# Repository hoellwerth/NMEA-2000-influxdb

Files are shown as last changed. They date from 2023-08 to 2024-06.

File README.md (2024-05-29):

# NMEA-2000-influxdb
An esp32 which posts traffic in the NMEA 2000 BUS to an InfluxDB 2.7 instance.

## Table of contents

- [Electrical](/Electrical): A KiCad project
- [Mechanical](/Mechanical): 3D files for casing etc.
- [Software](/Software): Platform IO Files

## Features

- [x] Listen for all known PGNs
- [x] Post data to an InfluxDB 2.7 instance
- [x] Save data to an SD-Card while offline 
- [ ] Use wifimanager

## Contribution

If you want to help with a feature or add something, just fork the repository, make your changes and open a Pull Request

## License

This project ist licensed under the [GNU GENERAL PUBLIC LICENSE](/LICENSE)

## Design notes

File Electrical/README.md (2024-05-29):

# Electrical

## Table of Contents
- [Electrical](https://github.com/hoellwerth/NMEA-2000-influxdb/tree/master/Electrical#electrical)
  - [Schematic](https://github.com/hoellwerth/NMEA-2000-influxdb/blob/master/Electrical/production/schematic.pdf) The KiCad Schematic

## Components-List

A list of all the electrical components I used for the project:

- ESP32-WROOM-32E
- CAN-Transeiver SN65HVD230
- SD-Card Slot
- LM7805
- AMS1117
- BME280

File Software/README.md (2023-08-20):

# Software

## Table of Contents

- [Software](#software)
  - [Table of Contents](#table-of-contents)
  - [Introduction](#introduction)
  - [Usage](#usage)
  - [Libraries](#libraries)
  - [How it works](#how-it-works)

## Introduction

This scipt is based on PlatformIO and will read all the data in the NMEA-2000 (N2k) BUS and will send it to an InfluxDB database. As this thing will be mainly operated in a marine environment, it will save data on an SD-Card as the boat will not always be connected to the internet and then write it to the database when it gets reconnected to a Wifi in harbor.

## Usage

To use this script, you will need to have a running InfluxDB instance. You can use the docker-compose combination of InfluxDB, Grafana and Telegraf from [here](https://github.com/nicolargo/docker-influxdb-grafana). You will also need to have a running N2k BUS. If you want to know which Hardware in particular, you can check out the [Hardware](../Hardware/README.md) section.

## Libraries

This script uses the following libraries:

- [ArduinoJson](https://arduinojson.org/)
- [InfluxDB-Client-for-Arduino](https://github.com/tobiasschuerg/InfluxDB-Client-for-Arduino)
- [NMEA2000](https://github.com/ttlappalainen/NMEA2000)
- [NMEA2000_esp32](https://github.com/ttlappalainen/NMEA2000_esp32)
- [RTCLib](https://github.com/adafruit/RTClib?utm_source=platformio&utm_medium=piohome)
- [Time](https://github.com/PaulStoffregen/Time?utm_source=platformio&utm_medium=piohome)

The relevant section in **platformio.ini**:
```
lib_deps = 
	tobiasschuerg/ESP8266 Influxdb@^3.13.1
	ttlappalainen/NMEA2000-library@^4.18.7
	ttlappalainen/NMEA2000_esp32@^1.0.3
	bblanchon/ArduinoJson@^6.21.2
	Wire
	paulstoffregen/Time@^1.6.1
	adafruit/RTClib@^2.1.1
```

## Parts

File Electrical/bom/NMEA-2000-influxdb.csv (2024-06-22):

Reference | Value | Datasheet | Footprint | Qty | DNP
C1,C3,C5,C6,C8,C9 | 0.1uF | ~ | Capacitor_THT:C_Disc_D5.0mm_W2.5mm_P5.00mm | 6
C2 | 0.1nF | ~ | Capacitor_THT:C_Disc_D5.0mm_W2.5mm_P5.00mm | 1
C4,C10,C11 | 22uF | ~ | Capacitor_THT:C_Radial_D4.0mm_H7.0mm_P1.50mm | 3
C7 | 0.33uF | ~ | Capacitor_THT:C_Disc_D5.0mm_W2.5mm_P5.00mm | 1
D1 | LED_Small | ~ | LED_THT:LED_D3.0mm | 1
D2,D3,D4,D5 | LED | ~ | LED_THT:LED_D3.0mm | 4
F1 | Polyfuse | ~ | Diode_SMD:D_1210_3225Metric_Pad1.42x2.65mm_HandSolder | 1
J1,J2,J3 | Conn_01x04 | ~ | -- mixed values -- | 3
J4 | Conn_01x03 | ~ | Connector_PinHeader_2.54mm:PinHeader_1x03_P2.54mm_Vertical | 1
J5 | Conn_02x08 | ~ | Connector_IDC:IDC-Header_2x08_P2.54mm_Vertical | 1
J6 | Micro_SD_Card | http://katalog.we-online.de/em/datasheet/693072010801.pdf | Connector_Card:microSD_HC_Hirose_DM3AT-SF-PEJM5 | 1
JP1,JP4 | Jumper_2_Open | ~ | Connector_PinHeader_2.54mm:PinHeader_1x02_P2.54mm_Vertical | 2
JP2,JP3 | Jumper_3_Bridged12 | ~ | Connector_PinHeader_2.54mm:PinHeader_1x03_P2.54mm_Vertical | 2
R1,R3,R5 | 10k | ~ | Resistor_THT:R_Axial_DIN0207_L6.3mm_D2.5mm_P10.16mm_Horizontal | 3
R2 | 3.3k | ~ | Resistor_THT:R_Axial_DIN0207_L6.3mm_D2.5mm_P10.16mm_Horizontal | 1
R4,R10 | 330R | ~ | Resistor_THT:R_Axial_DIN0207_L6.3mm_D2.5mm_P10.16mm_Horizontal | 2
R6 | 1.5k | ~ | Resistor_THT:R_Axial_DIN0207_L6.3mm_D2.5mm_P10.16mm_Horizontal | 1
R7 | 1.2k | ~ | Resistor_THT:R_Axial_DIN0207_L6.3mm_D2.5mm_P10.16mm_Horizontal | 1
R8 | 120R | ~ | Resistor_THT:R_Axial_DIN0207_L6.3mm_D2.5mm_P10.16mm_Horizontal | 1
R9 | 500R | ~ | Resistor_THT:R_Axial_DIN0207_L6.3mm_D2.5mm_P10.16mm_Horizontal | 1
SW1 | SW_Push | ~ | Button_Switch_THT:SW_PUSH_6mm | 1
U1 | BMP280 | https://ae-bst.resource.bosch.com/media/_tech/media/datasheets/BST-BMP280-DS001.pdf | Package_LGA:Bosch_LGA-8_2x2.5mm_P0.65mm_ClockwisePinNumbering | 1
U2 | LM7805_TO220 | https://www.onsemi.cn/PowerSolutions/document/MC7800-D.PDF | Package_TO_SOT_THT:TO-220-3_Vertical | 1
U3 | ESP32-WROOM-32E | https://www.espressif.com/sites/default/files/documentation/esp32-wroom-32e_esp32-wroom-32ue_datasheet_en.pdf | RF_Module:ESP32-WROOM-32D | 1
U4 | AMS1117-3.3 | http://www.advanced-monolithic.com/pdf/ds1117.pdf | Package_TO_SOT_SMD:SOT-223-3_TabPin2 | 1
U5 | SN65HVD230 | http://www.ti.com/lit/ds/symlink/sn65hvd230.pdf | Package_SO:SOIC-8_3.9x4.9mm_P1.27mm | 1

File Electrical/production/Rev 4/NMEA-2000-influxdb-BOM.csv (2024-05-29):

Reference | Value | Datasheet | Footprint | Qty | DNP | LCSC Part Number | Sourced
C1 | 0.33uF | ~ | Capacitor_THT:C_Disc_D5.0mm_W2.5mm_P5.00mm | 1 |  | C2761750 | yes
C2,C5,C8,C9,C10 | 0.1uF | ~ | Capacitor_THT:C_Disc_D5.0mm_W2.5mm_P5.00mm | 5 |  | C84772 | yes
C3,C4,C6 | 1uF | ~ | Capacitor_THT:C_Disc_D5.0mm_W2.5mm_P5.00mm | 3 |  | C5632429 | yes
C7 | 22uF | ~ | Capacitor_SMD:C_1206_3216Metric_Pad1.33x1.80mm_HandSolder | 1 |  | C12891 | yes
D1,D2,D3,D4,D5 | LED | ~ | LED_THT:LED_D3.0mm | 5 |  |  | yes
F1 | Polyfuse | ~ | Diode_SMD:D_1210_3225Metric_Pad1.42x2.65mm_HandSolder | 1 |  | C720080 | yes
J1 | Conn_01x04 | ~ | Connector:FanPinHeader_1x04_P2.54mm_Vertical | 1 |  |  | yes
J2 | DE9_Receptacle | ~ | Connector_Dsub:DSUB-9_Female_Horizontal_P2.77x2.84mm_EdgePinOffset9.90mm_Housed_MountingHolesOffset11.32mm | 1 |  | C19077337 | yes
J3 | Conn_01x04 |  | TerminalBlock_Phoenix:TerminalBlock_Phoenix_PT-1,5-4-5.0-H_1x04_P5.00mm_Horizontal | 1 |  |  | yes
J4 | Micro_SD_Card | http://katalog.we-online.de/em/datasheet/693072010801.pdf | Connector_Card:microSD_HC_Hirose_DM3AT-SF-PEJM5 | 1 |  | C114218 | yes
J5 | Conn_02x08 | ~ | Connector_IDC:IDC-Header_2x08_P2.54mm_Vertical | 1 |  |  | yes
JP1 | Jumper_2_Open | ~ | Connector_PinHeader_2.54mm:PinHeader_1x02_P2.54mm_Vertical | 1 |  |  | yes
JP2,JP3 | Jumper_3_Bridged12 | ~ | Connector_PinHeader_2.54mm:PinHeader_1x03_P2.54mm_Vertical | 2 |  |  | yes
R1 | 1.5k | ~ | Resistor_THT:R_Axial_DIN0204_L3.6mm_D1.6mm_P5.08mm_Horizontal | 1 |  |  | yes
R2 | 1.2k | ~ | Resistor_THT:R_Axial_DIN0204_L3.6mm_D1.6mm_P5.08mm_Horizontal | 1 |  |  | yesd
R3 | 500R | ~ | Resistor_THT:R_Axial_DIN0204_L3.6mm_D1.6mm_P5.08mm_Horizontal | 1 |  |  | yes
R4,R9 | 330R | ~ | Resistor_THT:R_Axial_DIN0204_L3.6mm_D1.6mm_P5.08mm_Horizontal | 2 |  |  | yes
R5 | 0R | ~ | Resistor_THT:R_Axial_DIN0204_L3.6mm_D1.6mm_P5.08mm_Horizontal | 1 |  |  | yes
R6,R8 | 10k | ~ | Resistor_THT:R_Axial_DIN0204_L3.6mm_D1.6mm_P5.08mm_Horizontal | 2 |  |  | yes
R7 | 120R | ~ | Resistor_THT:R_Axial_DIN0204_L3.6mm_D1.6mm_P5.08mm_Horizontal | 1 |  |  | yes
R10,R11 | 4.7k | ~ | Resistor_THT:R_Axial_DIN0204_L3.6mm_D1.6mm_P5.08mm_Horizontal | 2 |  |  | yes
SW1 | SW_Push | ~ | Button_Switch_THT:SW_PUSH_6mm | 1 |  |  | yes
U1 | LM7805_TO220 | https://www.onsemi.cn/PowerSolutions/document/MC7800-D.PDF | Package_TO_SOT_THT:TO-220-3_Vertical | 1 |  |  | yes
U2 | AP2112K-3.3 | https://www.diodes.com/assets/Datasheets/AP2112.pdf | Package_TO_SOT_SMD:SOT-23-5 | 1 |  |  | yes
U3 | SN65HVD230 | http://www.ti.com/lit/ds/symlink/sn65hvd230.pdf | Package_SO:SOIC-8_3.9x4.9mm_P1.27mm | 1 |  |  | yes
U4 | ESP32-WROOM-32E | https://www.espressif.com/sites/default/files/documentation/esp32-wroom-32e_esp32-wroom-32ue_datasheet_en.pdf | RF_Module:ESP32-WROOM-32D | 1 |  | C701341 | yes
U5 | BME280 | https://www.bosch-sensortec.com/media/boschsensortec/downloads/datasheets/bst-bme280-ds002.pdf | Package_LGA:Bosch_LGA-8_2.5x2.5mm_P0.65mm_ClockwisePinNumbering | 1 |  | C92489 | yes

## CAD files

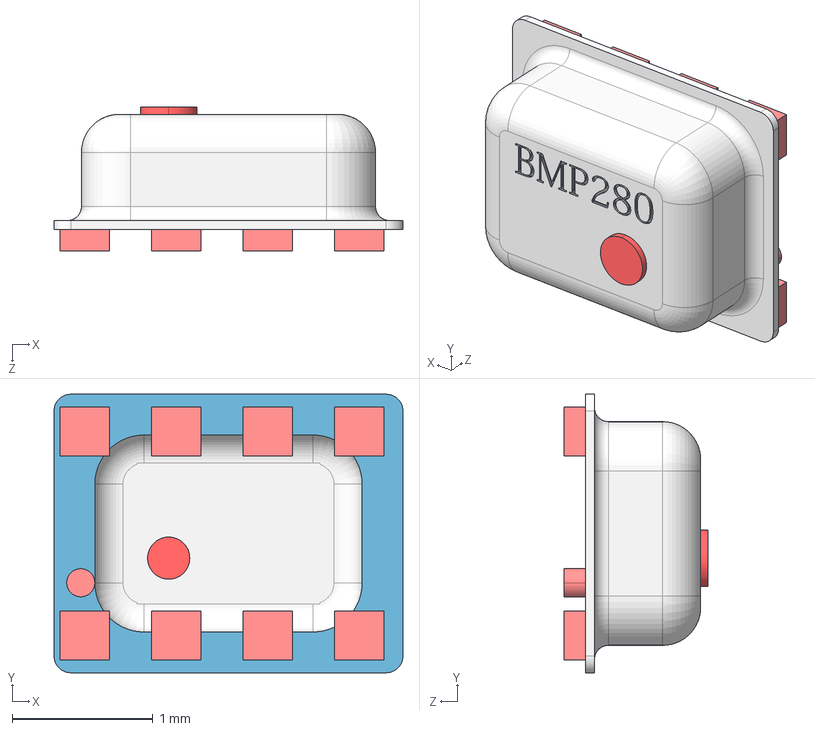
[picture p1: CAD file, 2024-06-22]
Electrical/3D-Models/BMP-280.STEP
2.48 x 1.98 x 1.02 mm

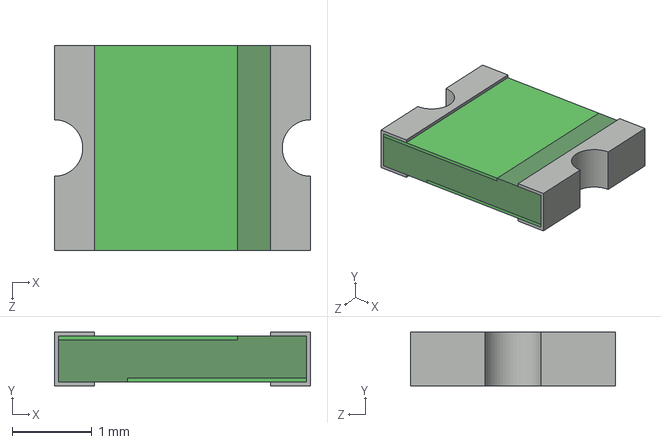
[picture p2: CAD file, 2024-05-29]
Electrical/3D-Models/User Library-Fuse1210.step
3.21 x 0.675 x 2.58 mm

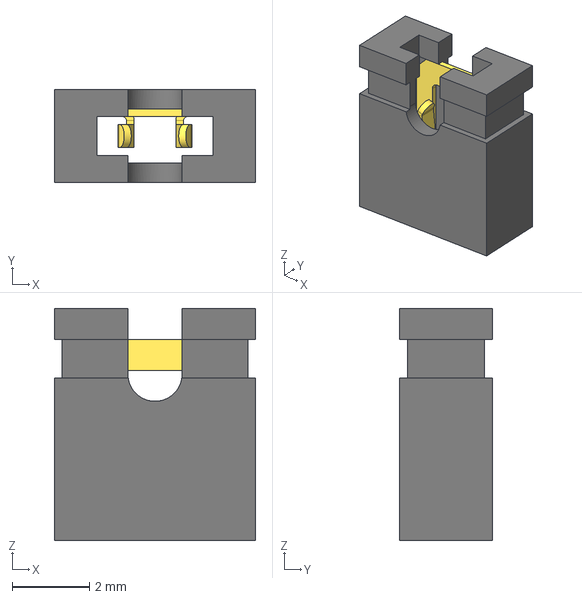
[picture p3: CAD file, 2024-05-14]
Electrical/3D-Models/Jumper.step
5.20 x 2.40 x 6.00 mm

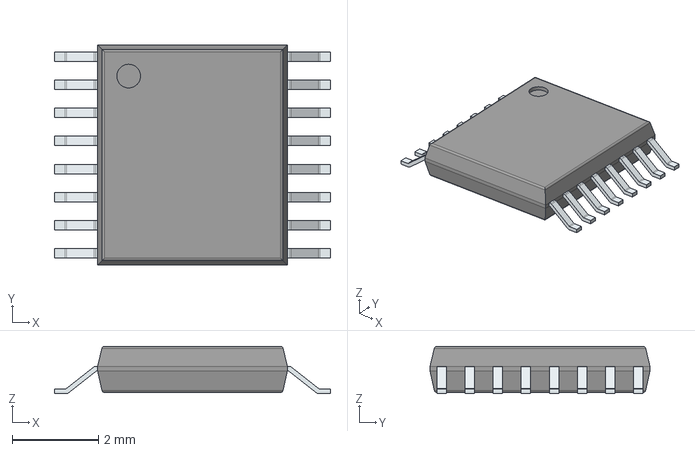
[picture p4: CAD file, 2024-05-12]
Electrical/3D-Models/S-8254AAVFT-TB-U.stp
6.40 x 5.10 x 1.10 mm
PinsArrayLR

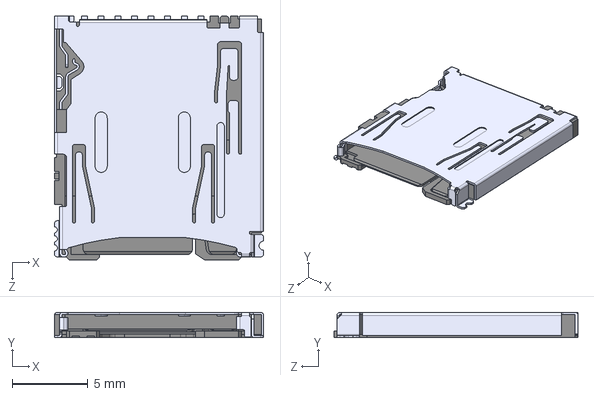
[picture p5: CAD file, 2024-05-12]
Electrical/3D-Models/DM3AT-SF-PEJM5--3DModel-STEP-418109.STEP
13.8 x 1.68 x 16.2 mm

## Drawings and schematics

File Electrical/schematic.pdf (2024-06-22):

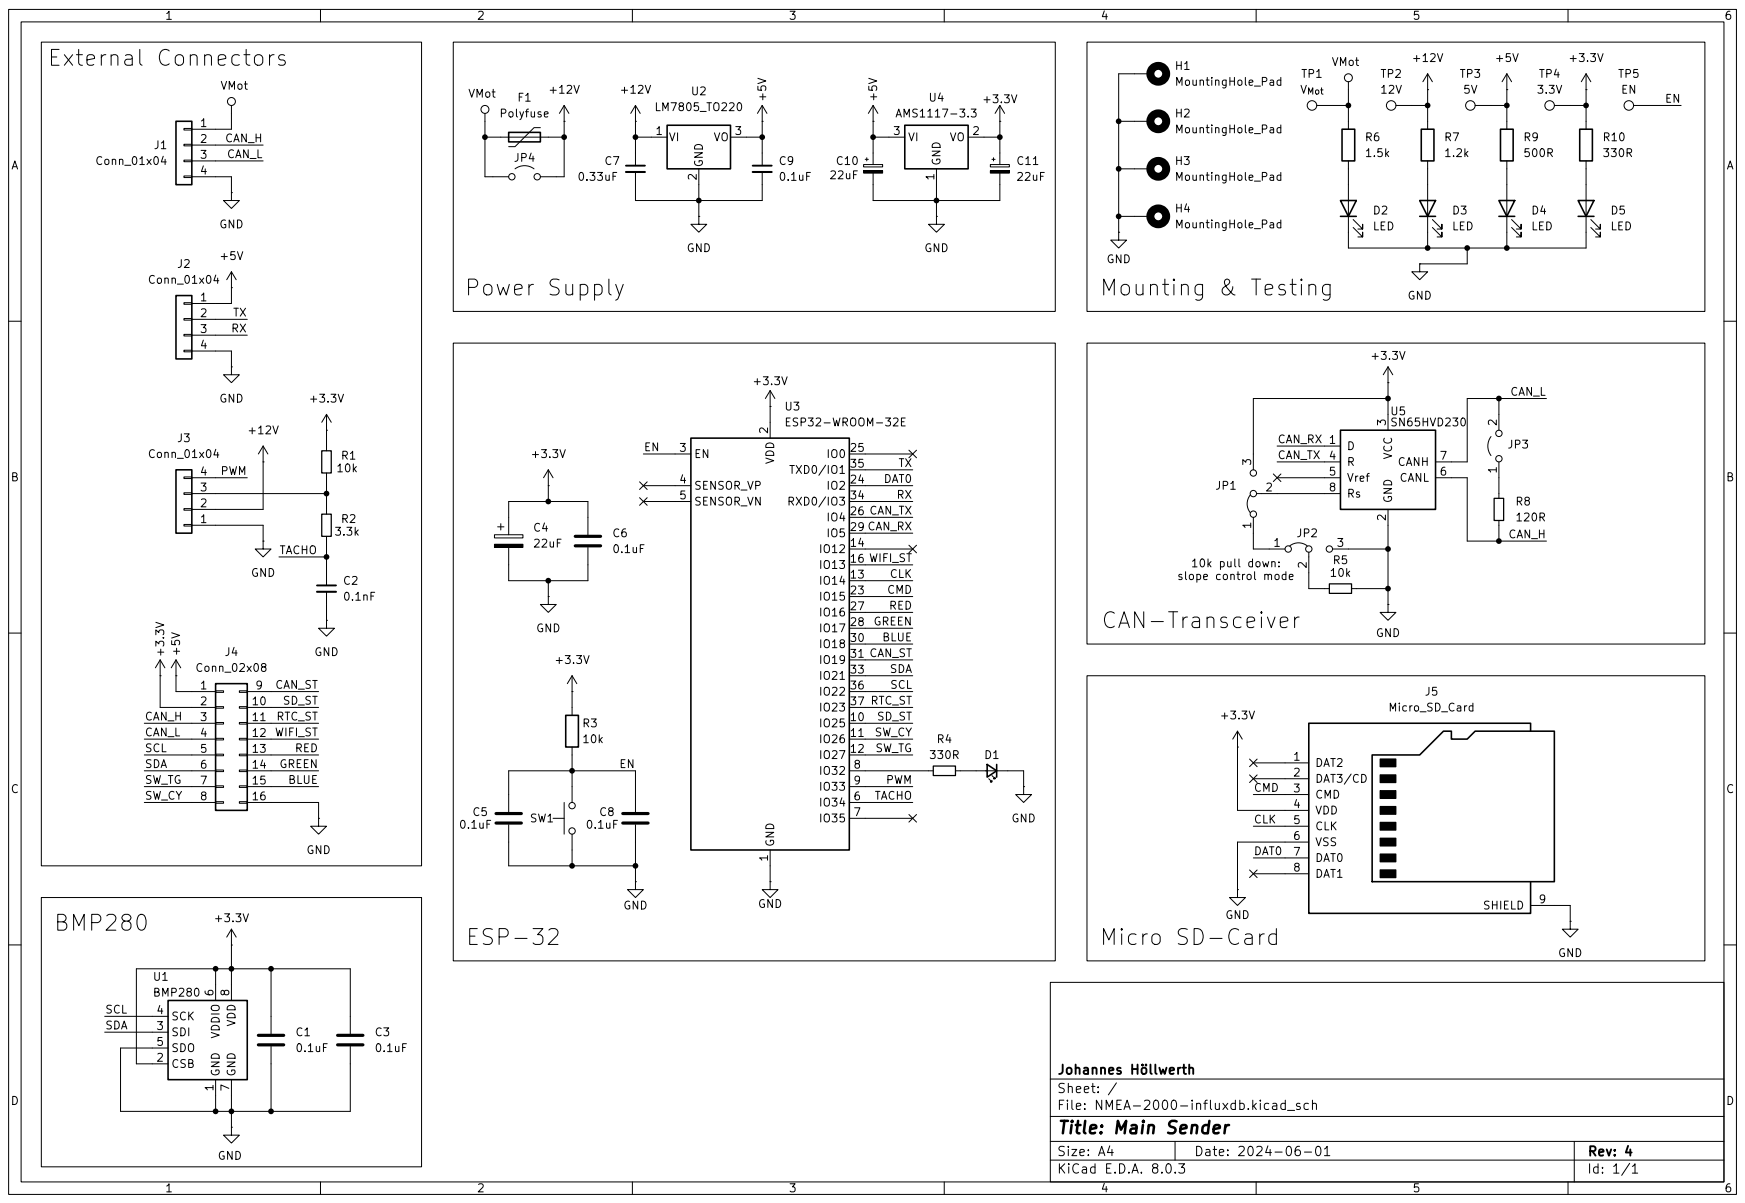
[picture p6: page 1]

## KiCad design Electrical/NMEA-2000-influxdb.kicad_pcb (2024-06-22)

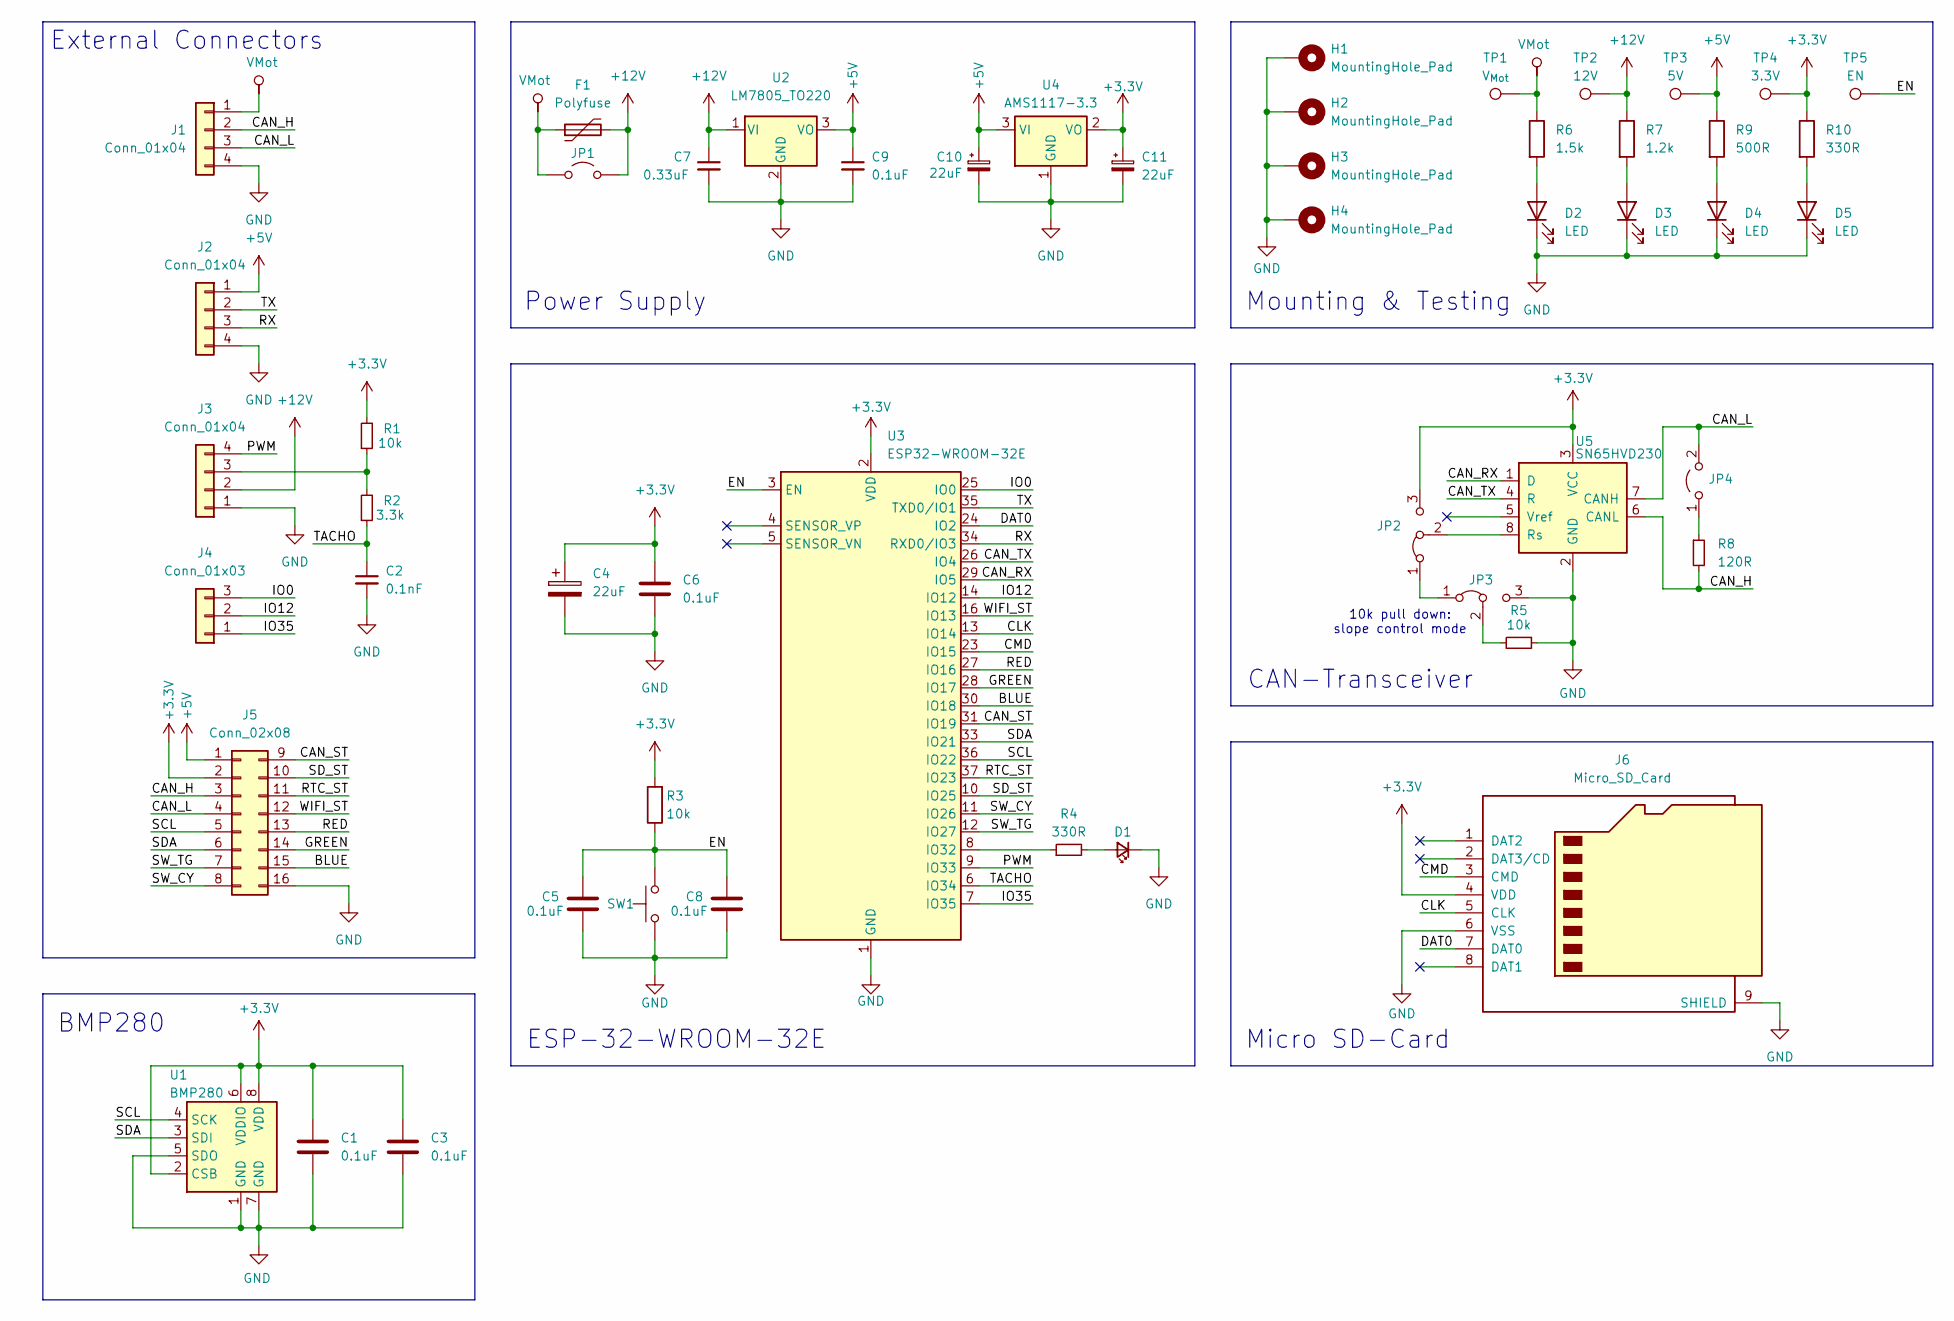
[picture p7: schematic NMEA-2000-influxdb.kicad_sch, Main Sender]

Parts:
C1, C3, C5, C6, C8, C9: 0.1uF; C_Disc_D5.0mm_W2.5mm_P5.00mm
C2: 0.1nF; C_Disc_D5.0mm_W2.5mm_P5.00mm
C4, C10, C11: 22uF; C_Radial_D4.0mm_H7.0mm_P1.50mm
C7: 0.33uF; C_Disc_D5.0mm_W2.5mm_P5.00mm
D1: LED_Small; LED_D3.0mm
D2, D3, D4, D5: LED; LED_D3.0mm
F1: Polyfuse; D_1210_3225Metric_Pad1.42x2.65mm_HandSolder
H1, H2, H3, H4: MountingHole_Pad; MountingHole_3mm_Pad_Via
J1: Conn_01x04; TerminalBlock_Phoenix_PT-1,5-4-5.0-H_1x04_P5.00mm_Horizontal
J2: Conn_01x04; PinSocket_1x04_P2.54mm_Horizontal
J3: Conn_01x04; FanPinHeader_1x04_P2.54mm_Vertical
J4: Conn_01x03; PinHeader_1x03_P2.54mm_Vertical
J5: Conn_02x08; IDC-Header_2x08_P2.54mm_Vertical
J6: Micro_SD_Card; microSD_HC_Hirose_DM3AT-SF-PEJM5
JP1, JP4: Jumper_2_Open; PinHeader_1x02_P2.54mm_Vertical
JP2, JP3: Jumper_3_Bridged12; PinHeader_1x03_P2.54mm_Vertical
R1, R3, R5: 10k; R_Axial_DIN0207_L6.3mm_D2.5mm_P10.16mm_Horizontal
R2: 3.3k; R_Axial_DIN0207_L6.3mm_D2.5mm_P10.16mm_Horizontal
R4, R10: 330R; R_Axial_DIN0207_L6.3mm_D2.5mm_P10.16mm_Horizontal
R6: 1.5k; R_Axial_DIN0207_L6.3mm_D2.5mm_P10.16mm_Horizontal
R7: 1.2k; R_Axial_DIN0207_L6.3mm_D2.5mm_P10.16mm_Horizontal
R8: 120R; R_Axial_DIN0207_L6.3mm_D2.5mm_P10.16mm_Horizontal
R9: 500R; R_Axial_DIN0207_L6.3mm_D2.5mm_P10.16mm_Horizontal
SW1: SW_Push; SW_PUSH_6mm
TP1: V_{Mot}; TestPoint_Pad_2.5x2.5mm
TP2: 12V; TestPoint_Pad_2.5x2.5mm
TP3: 5V; TestPoint_Pad_2.5x2.5mm
TP4: 3.3V; TestPoint_Pad_2.5x2.5mm
TP5: EN; TestPoint_Pad_2.5x2.5mm
U1: BMP280; Bosch_LGA-8_2x2.5mm_P0.65mm_ClockwisePinNumbering
U2: LM7805_TO220; TO-220-3_Vertical
U3: ESP32-WROOM-32E; ESP32-WROOM-32D
U4: AMS1117-3.3; SOT-223-3_TabPin2
U5: SN65HVD230; SOIC-8_3.9x4.9mm_P1.27mm

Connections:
+3.3V: C1.1, C3.1, C4.1, C6.1, C11.1, J5.2, J6.4 (VDD), JP2.3 (B), R1.2, R3.2, R10.1, TP4.1, U1.2 (CSB), U1.6 (VDDIO), U1.8 (VDD), U3.2 (VDD), U4.2 (VO), U5.3 (VCC)
+5V: C9.1, C10.1, J2.1, J5.1, R9.1, TP3.1, U2.3 (VO), U4.3 (VI)
+12V: C7.1, F1.2, J3.2, JP1.2 (B), R7.1, TP2.1, U2.1 (VI)
/BLUE: J5.15, U3.30 (IO18)
/CAN_H: J1.2, J5.3, R8.2, U5.6 (CANL)
/CAN_L: J1.3, J5.4, JP4.2 (B), U5.7 (CANH)
/CAN_RX: U3.29 (IO5), U5.1 (D)
/CAN_ST: J5.9, U3.31 (IO19)
/CAN_TX: U3.26 (IO4), U5.4 (R)
/CLK: J6.5 (CLK), U3.13 (IO14)
/CMD: J6.3 (CMD), U3.23 (IO15)
/DAT0: J6.7 (DAT0), U3.24 (IO2)
/EN: C5.2, C8.2, R3.1, SW1.2, TP5.1, U3.3 (EN)
/GREEN: J5.14, U3.28 (IO17)
/IO0: J4.3, U3.25 (IO0)
/IO12: J4.2, U3.14 (IO12)
/IO35: J4.1, U3.7 (IO35)
/PWM: J3.4, U3.9 (IO33)
/RED: J5.13, U3.27 (IO16)
/RTC_ST: J5.11, U3.37 (IO23)
/RX: J2.3, U3.34 (RXD0/IO3)
/SCL: J5.5, U1.4 (SCK), U3.36 (IO22)
/SDA: J5.6, U1.3 (SDI), U3.33 (IO21)
/SD_ST: J5.10, U3.10 (IO25)
/SW_CY: J5.8, U3.11 (IO26)
/SW_TG: J5.7, U3.12 (IO27)
/TACHO: C2.1, R2.1, U3.6 (IO34)
/TX: J2.2, U3.35 (TXD0/IO1)
/WIFI_ST: J5.12, U3.16 (IO13)
GND: C1.2, C2.2, C3.2, C4.2, C5.1, C6.2, C7.2, C8.1, C9.2, C10.2, C11.2, D1.1 (K), D2.1 (K), D3.1 (K), D4.1 (K), D5.1 (K), H1.1, H2.1, H3.1, H4.1, J1.4, J2.4, J3.1, J5.16, J6.6 (VSS), J6.9 (SHIELD), JP3.3 (B), R5.1, SW1.1, U1.1 (GND), U1.5 (SDO), U1.7 (GND), U2.2 (GND), U3.1 (GND), U3.15 (GND), U3.38 (GND), U3.39 (GND), U4.1 (GND), U5.2 (GND)
unnamed: D1.2 (A), R4.2
unnamed: D2.2 (A), R6.2
unnamed: D3.2 (A), R7.2
unnamed: D4.2 (A), R9.2
unnamed: D5.2 (A), R10.2
unnamed: J3.3, R1.1, R2.2
unnamed: JP2.1 (A), JP3.1 (A)
unnamed: JP2.2 (C), U5.8 (Rs)
unnamed: JP3.2 (C), R5.2
unnamed: JP4.1 (A), R8.1
unnamed: R4.1, U3.8 (IO32)
VMot: F1.1, J1.1, JP1.1 (A), R6.1, TP1.1

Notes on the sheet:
Power Supply
CAN-Transceiver
Mounting & Testing
ESP-32-WROOM-32E
10k pull down: slope control mode
Micro SD-Card
BMP280
External Connectors

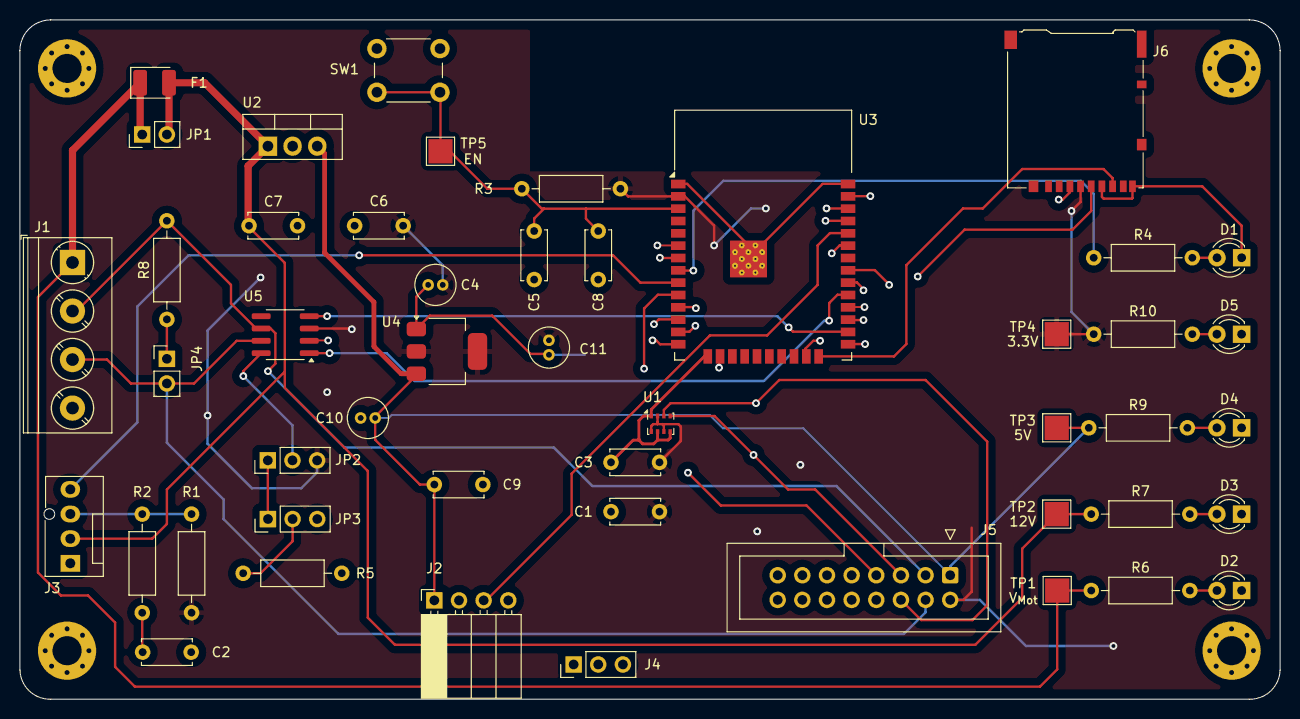
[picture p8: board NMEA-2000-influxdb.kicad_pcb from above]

Board: 4 copper layers, 129.9 x 70.0 mm, 52 parts (0 on the bottom side), 42 nets.

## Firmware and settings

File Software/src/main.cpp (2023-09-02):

#define DEVICE "ESP32"

#define ESP32_CAN_TX_PIN GPIO_NUM_17  // Set CAN TX port to 17
#define ESP32_CAN_RX_PIN GPIO_NUM_4  // Set CAN RX port to 4

#define WRITE_PRECISION WritePrecision::S
#define MAX_BATCH_SIZE 10
#define WRITE_BUFFER_SIZE 30

#define WIFI_SSID "JojoNet"
#define WIFI_PASSWORD "Sennahoj08!?"

#include <WiFiMulti.h>
#include <InfluxDbClient.h>
#include <Arduino.h>
#include <ArduinoJson.h>
#include <Preferences.h>
#include <NMEA2000_CAN.h>
#include <N2kMessages.h>
#include <queue/queue.h>
#include <iostream>
#include <RTClib.h>
#include <Wire.h>
#include <TimeLib.h>

// SD-Card helper functions
#include "../src/sDCard/sdCard.h"

// Include Buffer
#include "../src/buffer/buffer.h"

// To store last Node Address
int NodeAddress;

// Nonvolatile storage on ESP32 - To store LastDeviceAddress
Preferences preferences;

RTC_DS3231 rtc;

WiFiMulti wifiMulti;

unsigned long previousMillis = 0;
unsigned long interval = 30000;

bool previous = false;

time_t currentTime;

// Set the information for other bus devices, which messages we support
const unsigned long ReceiveMessages[] PROGMEM = {
  126992L, // System time
  127250L, // Heading
  127258L, // Magnetic variation
  128259L, // Boat speed
  128267L, // Depth
  129025L, // Position
  129026L, // COG and SOG
  129029L, // GNSS
  130306L, // Wind
  128275L, // Log
  127245L, // Rudder
  127505L, // Fluids
  0
};

const char* months[12] = {
  "Jan",
  "Feb",
  "Mar",
  "Apr",
  "May",
  "Jun",
  "Jul",
  "Aug",
  "Sep",
  "Oct",
  "Nov",
  "Dec"
};

void newNetwork() {
  general.clearTags();

  // Add constant tags
  general.addTag("SSID", WiFi.SSID());

  // Check server connection
  if (client.validateConnection()) {
    Serial.print("Connected to InfluxDB: ");
    Serial.println(client.getServerUrl());
    return;
  }

  Serial.print("InfluxDB connection failed: ");
  Serial.println(client.getLastErrorMessage());
}

bool connectWifi() {
  Serial.println("Connecting to WiFi");

  // Set Wifi to stationary mdoe
  WiFi.mode(WIFI_STA);
  wifiMulti.addAP(WIFI_SSID, WIFI_PASSWORD);

  if (wifiMulti.run() == WL_CONNECTED) {
    // Successfully connected
    Serial.print("Connected to ");
    Serial.println(WiFi.SSID());

    // Synchronize time with NTP servers and set timezone
    configTzTime("CET-1CEST,M3.5.0,M10.5.0/3", "pool.ntp.org", "time.nis.gov");

    // Wait till time is synced
    Serial.print("Syncing time");
    int i = 0;
    while (time(nullptr) < 1000000000l && i < 40) {
      Serial.print(".");
      delay(500);
      i++;
    }
    Serial.println();

    // Show time
    time_t tnow = time(nullptr);
    Serial.print("Synchronized time: ");
    Serial.println(ctime(&tnow));

    currentTime = tnow;

    Serial.print("Current time: ");
    Serial.println(currentTime);

    // Set time on RTC
    char date[32];
    sprintf(
      date,
      "%03s %02d %02d",
      months[month(currentTime) - 1],
      day(currentTime),
      year(currentTime)
    );

    char time[32];
    sprintf(
      time,
      "%02d:%02d:%02d",
      hour(currentTime),
      minute(currentTime),
      second(currentTime)
    );

    Serial.print("Time: ");
    Serial.print(date);
    Serial.print(" ");
    Serial.println(time);

    rtc.adjust(DateTime(F(date), F(time)));
    
    Serial.print("RTC Temp: ");
    Serial.println(rtc.getTemperature());

    Serial.print("RTC time: ");
    Serial.println(rtc.now().unixtime());

    // Update influxdb connection
    newNetwork();

    return true;
  }
  
  Serial.println("Unable to connect to a Wifi");

  return false;
}


void handleBatteryStatus(const tN2kMsg &N2kMsg) {
  unsigned char SID;
  unsigned char BatteryInstance;
  double BatteryVoltage;
  double BatteryCurrent;
  double BatteryTemperature;

  if (!ParseN2kPGN127508(N2kMsg, BatteryInstance, BatteryVoltage, BatteryCurrent, BatteryTemperature, SID)) {
    return;
  }

  // If main battery
  if (BatteryInstance == 0.0) {
    Serial.printf("MainBattery: (Voltage: %3.1f V, Current: %3.1f A, Temp: %3.1f C)\n", BatteryVoltage, BatteryCurrent, KelvinToC(BatteryTemperature));

    if (wifiMulti.run() == WL_CONNECTED && previous) {
      previous = false;
      writeFromBuffer();
    }

    mainBattery.clearFields(); 

    mainBattery.addField("voltage", BatteryVoltage);
    mainBattery.addField("current", BatteryCurrent);
    mainBattery.addField("temperature", KelvinToC(BatteryTemperature));
    mainBattery.addField("power", BatteryVoltage * BatteryCurrent);

    // Write to influx
    client.pointToLineProtocol(starterBattery);

    // Catch errors
    if (!client.writePoint(mainBattery)) {
      Serial.print("InfluxDB write failed: ");
      Serial.println(client.getLastErrorMessage());

      // Get current time
      DateTime now = rtc.now();

      char voltage[200];
      sprintf(voltage, "%2.13f", BatteryVoltage);
      writeToBuffer(now.unixtime(), voltage, "/main_battery_voltage");

      char current[200];
      sprintf(current, "%2.13f", BatteryCurrent);
      writeToBuffer(now.unixtime(), current, "/main_battery_current");

      char temperature[200];
      sprintf(temperature, "%2.13f", KelvinToC(BatteryTemperature));
      writeToBuffer(now.unixtime(), temperature, "/main_battery_temperature");
    }

    return;
  }

  // If starter battery
  if (BatteryInstance == 1.0) {
    Serial.printf("Starter Battery: (Voltage: %3.1f V, Current: %3.1f A, Temp: %3.1f C)\n", BatteryVoltage, BatteryCurrent, KelvinToC(BatteryTemperature));

    if (wifiMulti.run() == WL_CONNECTED && previous) {
      previous = false;
      writeFromBuffer();
    }

    starterBattery.clearFields();

    starterBattery.addField("voltage", BatteryVoltage);
    starterBattery.addField("current", BatteryCurrent);
    starterBattery.addField("temperature", KelvinToC(BatteryTemperature));
    starterBattery.addField("power", BatteryVoltage * BatteryCurrent);
    
    // Write to influx
    client.pointToLineProtocol(starterBattery);

    // Catch errors
    if (!client.writePoint(starterBattery)) {
      Serial.print("InfluxDB write failed: ");
      Serial.println(client.getLastErrorMessage());

      // Get current time
      DateTime now = rtc.now();

      char voltage[200];
      sprintf(voltage, "%2.13f", BatteryVoltage);
      writeToBuffer(now.unixtime(), voltage, "/starter_battery_voltage");

      char current[200];
      sprintf(current, "%2.13f", BatteryCurrent);
      writeToBuffer(now.unixtime(), current, "/starter_battery_current");

      char temperature[200];
      sprintf(temperature, "%2.13f", KelvinToC(BatteryTemperature));
      writeToBuffer(now.unixtime(), temperature, "/starter_battery_temperature");
    }

    return;
  }
}

// Function to check if SourceAddress has changed (due to address conflict on bus)
void CheckSourceAddressChange() {
  int SourceAddress = NMEA2000.GetN2kSource();

  if (SourceAddress != NodeAddress) { // Save potentially changed Source Address to NVS memory
    NodeAddress = SourceAddress;      // Set new Node Address (to save only once)
    preferences.begin("nvs", false);
    preferences.putInt("LastNodeAddress", SourceAddress);
    preferences.end();
    Serial.printf("Address Change: New Address=%d\n", SourceAddress);
  }
}

void MyHandleNMEA2000Msg(const tN2kMsg &N2kMsg) {

  switch (N2kMsg.PGN) {
    case 127508L: handleBatteryStatus(N2kMsg);
  }
}

void setup() {
  uint8_t chipid[6];
  uint32_t id = 0;
  int i = 0;

  // Init USB serial port
  Serial.begin(115200);
  delay(10);

	// init RTC
  if (!rtc.begin()) {
    Serial.println("Couldn't find RTC");
    Serial.flush();
    while (1) delay(10);
  }
  
  // Enable client side influxdb timestamps - set time precision to milliseconds
  client.setWriteOptions(WriteOptions().writePrecision(WRITE_PRECISION).batchSize(MAX_BATCH_SIZE).bufferSize(WRITE_BUFFER_SIZE));

  // Reserve enough buffer for sending all messages.
  NMEA2000.SetN2kCANMsgBufSize(8);
  NMEA2000.SetN2kCANReceiveFrameBufSize(150);
  NMEA2000.SetN2kCANSendFrameBufSize(150);

  // Generate unique number from chip id
  esp_efuse_mac_get_default(chipid);
  for (i = 0; i < 6; i++) id += (chipid[i] << (7 * i));

  // Set product information
  NMEA2000.SetProductInformation(
    "1", // Manufacturer's Model serial code
    100, // Manufacturer's product code
    "NMEA Reader",  // Manufacturer's Model ID
    "1.0.2.25 (2019-07-07)",  // Manufacturer's Software version code
    "1.0.2.0 (2019-07-07)" // Manufacturer's Model version
  );
  
  // Set device information
  NMEA2000.SetDeviceInformation(id,  // Unique number. Use e.g. Serial number.
    131, // Device function=NMEA 2000 to Analog Gateway. See codes on http://www.nmea.org/Assets/20120726%20nmea%202000%20class%20&%20function%20codes%20v%202.00.pdf
    25,  // Device class=Inter/Intranetwork Device. See codes on  http://www.nmea.org/Assets/20120726%20nmea%202000%20class%20&%20function%20codes%20v%202.00.pdf
    2046 // Just choosen free from code list on http://www.nmea.org/Assets/20121020%20nmea%202000%20registration%20list.pdf
  );

  preferences.begin("nvs", false);                          // Open nonvolatile storage (nvs)
  NodeAddress = preferences.getInt("LastNodeAddress", 34);  // Read stored last NodeAddress, default 34
  preferences.end();
  Serial.printf("NodeAddress=%d\n", NodeAddress);

  // If you also want to see all traffic on the bus use N2km_ListenAndNode instead of N2km_NodeOnly below
  NMEA2000.SetMode(tNMEA2000::N2km_ListenOnly, NodeAddress);
  NMEA2000.ExtendReceiveMessages(ReceiveMessages);
  NMEA2000.SetMsgHandler(MyHandleNMEA2000Msg);

  NMEA2000.Open();
  delay(200);

  setupSD();

  connectWifi();
}


void loop() {

  // If not online - try connecting to a wifi
  unsigned long currentMillis = millis();

  // if WiFi is down, try reconnecting
  if ((wifiMulti.run() != WL_CONNECTED) && (currentMillis - previousMillis >=interval)) {
    Serial.print(millis());
    Serial.println("Reconnecting to WiFi...");
    WiFi.disconnect();
    WiFi.reconnect();
    previousMillis = currentMillis;

    previous = true;
  }

  // Parse the N2k messages
  NMEA2000.ParseMessages();

  // Check if adress has changed
  CheckSourceAddressChange();

  // Dummy to empty input buffer to avoid board to stuck with e.g. NMEA Reader
  if ( Serial.available() ) {
    Serial.read();
  }

  delay(1);
}

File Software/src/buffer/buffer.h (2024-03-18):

#include "Arduino.h"
#include <InfluxDbClient.h>
#include <InfluxDbClient.h>

// SD-Card helper functions
#include "../src/sDCard/sdCard.h"

#define INFLUXDB_URL "http://cloud.hoellwerth.eu:8086"
#define INFLUXDB_TOKEN "h8S4V-g_bvHkhf11t276cOQ8-pxJhUtPGAiF9He1sDyU3Lu1Bmnwjx0__5eb2kIoWn2-iWB8Z3ofQQa9u3G1VA=="
#define INFLUXDB_ORG "554b5bb375690e45"
#define INFLUXDB_BUCKET "boat"

// Setup Influxdb Client
InfluxDBClient client(INFLUXDB_URL, INFLUXDB_ORG, INFLUXDB_BUCKET, INFLUXDB_TOKEN);

// Create influxdb sensor points
Point mainBattery("main_battery");
Point starterBattery("starter_battery");
Point general("general");

// Write data to buffer
void writeToBuffer(time_t timestamp, const char* data, const char* path) {

  Serial.print("Path: ");
  Serial.println(path);

  // Append data to SD-Card
  char timestampChar[100];
  sprintf(timestampChar, "%2.13f", timestamp);

  Serial.print("Timestamp: ");
  Serial.println(timestampChar);

  std::string pathString = path;

  std::string timestampPathString = pathString + "_timestamps.txt";

  char* timestampPath = { new char[timestampPathString.length() + 1] };
  strcpy(timestampPath, timestampPathString.c_str());

  Serial.print("TimestampPath: ");
  Serial.println(timestampPath);

  std::string dataPathString = pathString + "_data.txt";

  char* dataPath = { new char[dataPathString.length() + 1] };
  strcpy(dataPath, dataPathString.c_str());

  Serial.print("DataPath: ");
  Serial.println(dataPath);

  appendFile(SD, timestampPath, timestampChar);
  appendFile(SD, dataPath, data);
}

// Writes entire data from SD-Card to influxdb
void writeFromBuffer() {
  Serial.println("Writing from buffer");
  
  // Main battery

  // Voltage

  const char* rawMainBatteryVoltageTimestamps = readFile(SD, "/main_battery_voltage_timestamps.txt");
  const char* rawMainBatteryVoltageData = readFile(SD, "/main_battery_voltage_data.txt");

  // Iterate through timestamps every 16 characters is a new timestamp

  for (int i = 0; i < strlen(rawMainBatteryVoltageTimestamps); i += 16) {
    char timestamp[15];
    strncpy(timestamp, rawMainBatteryVoltageTimestamps + i, 14);
    timestamp[14] = '\0';

    char data[16];
    strncpy(data, rawMainBatteryVoltageData + i, 14);
    data[14] = '\0';

    Serial.print("Timestamp: ");
    Serial.println(timestamp);

    Serial.print("Data: ");
    Serial.println(data);

    mainBattery.clearFields();

    const char* finalTimestamp = timestamp;

    mainBattery.setTime(finalTimestamp);

    float voltage = atof(data);
    voltage = (float)((int)(voltage * 100 + .5)) / 100;

    mainBattery.addField("voltage", voltage);

    // Write to influx
    client.pointToLineProtocol(mainBattery);

    // Catch errors
    if (!client.writePoint(mainBattery)) {
      Serial.print("InfluxDB write failed: ");
      Serial.println(client.getLastErrorMessage());

      writeToBuffer(atof(timestamp), data, "/main_battery_voltage");
    }
  }

  // Current

  const char* rawMainBatteryCurrentTimestamps = readFile(SD, "/main_battery_current_timestamps.txt");
  const char* rawMainBatteryCurrentData = readFile(SD, "/main_battery_current_data.txt");

  // Iterate through timestamps every 15 characters is a new timestamp

  for (int i = 0; i < strlen(rawMainBatteryCurrentTimestamps); i+=15) {
    char timestamp[15];
    strncpy(timestamp, rawMainBatteryCurrentTimestamps + i, 14);
    timestamp[14] = '\0';

    char data[15];
    strncpy(data, rawMainBatteryCurrentData + i, 14);
    data[14] = '\0';

    Serial.print("Timestamp: ");
    Serial.println(timestamp);

    Serial.print("Data: ");
    Serial.println(data);

    mainBattery.clearFields();

    const char* finalTimestamp = timestamp;

    mainBattery.setTime(finalTimestamp);

    float current = atof(data);
    current = (float)((int)(current * 100 + .5)) / 100;

    mainBattery.addField("current", current);

    // Write to influx
    client.pointToLineProtocol(mainBattery);

    // Catch errors
    if (!client.writePoint(mainBattery)) {
      Serial.print("InfluxDB write failed: ");
      Serial.println(client.getLastErrorMessage());

      writeToBuffer(atof(timestamp), data, "/main_battery_current");
    }
  }

  // Temperature

  const char* rawMainBatteryTemperatureTimestamps = readFile(SD, "/main_battery_temperature_timestamps.txt");
  const char* rawMainBatteryTemperatureData = readFile(SD, "/main_battery_temperature_data.txt");

  // Iterate through timestamps every 15 characters is a new timestamp

  for (int i = 0; i < strlen(rawMainBatteryTemperatureTimestamps); i+=15) {
    char timestamp[15];
    strncpy(timestamp, rawMainBatteryTemperatureTimestamps + i, 14);
    timestamp[14] = '\0';

    char data[15];
    strncpy(data, rawMainBatteryTemperatureData + i, 14);
    data[14] = '\0';

    Serial.print("Timestamp: ");
    Serial.println(timestamp);

    Serial.print("Data: ");
    Serial.println(data);

    mainBattery.clearFields();

    const char* finalTimestamp = timestamp;

    mainBattery.setTime(finalTimestamp);

    float temperature = atof(data);
    temperature = (float)((int)(temperature * 100 + .5)) / 100;


    mainBattery.addField("temperature", temperature);

    // Write to influx
    client.pointToLineProtocol(mainBattery);

    // Catch errors
    if (!client.writePoint(mainBattery)) {
      Serial.print("InfluxDB write failed: ");
      Serial.println(client.getLastErrorMessage());

      writeToBuffer(atof(timestamp), data, "/main_battery_temperature");
    }
  }
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

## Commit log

2023-05-15 Added Arduino script
2023-05-15 Added KiCad Project
2023-05-15 Added KiCad Schematic
    [NMEA-2000-influxdb.kicad_sch]
2023-05-15 Added KiCad PCB
    [NMEA-2000-influxdb.kicad_pcb]
2023-06-08 Added Voltage to Influx
2023-06-09 Added Current and Temp to Influx
2023-06-11 Updated KiCad Project
2023-06-11 Updated KiCad Schematic
    [NMEA-2000-influxdb.kicad_sch]
2023-06-12 Moved KiCad project into 'Electrical' Folder
    [NMEA-2000-influxdb.kicad_pcb, NMEA-2000-influxdb.kicad_sch]
2023-06-16 Added client side timestamps
    Enablef client side influxdb timestamps - set time precision to milliseconds
2023-06-24 Fixed calling of writeFromBuffer
    [NMEA-2000-influxdb.ino]
2023-06-24 Removed debug print of wifi status
2023-06-26 Prepared merge
    [NMEA-2000-influxdb.kicad_pcb, NMEA-2000-influxdb.kicad_sch]
2023-07-16 Added SN65HVD230 Module to schematic
    [NMEA-2000-influxdb.kicad_sch]
2023-07-16 Added RTC-Module to schematic
    [NMEA-2000-influxdb.kicad_sch]
2023-07-16 Added BMP280-Module
    [NMEA-2000-influxdb.kicad_sch]
2023-07-16 Added SD-Card-Module to Schematic
    [NMEA-2000-influxdb.kicad_sch]
2023-07-18 Added Power Connector
    [NMEA-2000-influxdb.kicad_sch]
2023-07-18 Added esp32 Footprint
2023-07-21 Added Wire Library
2023-07-22 Removed BMP280 Sensor
    [NMEA-2000-influxdb.kicad_sch]
2023-11-21 Replaced SN65HVD230-Module with SN65HVD230
    [NMEA-2000-influxdb.kicad_pcb, NMEA-2000-influxdb.kicad_sch]
2023-11-23 Added external connectors
    [NMEA-2000-influxdb.kicad_sch]
2023-11-23 Added board
    [NMEA-2000-influxdb.kicad_pcb]
2023-11-26 Updated board and added heatsink
    [NMEA-2000-influxdb.kicad_pcb, NMEA-2000-influxdb.kicad_sch]
2023-12-12 Added Seven segment displays
    [NMEA-2000-influxdb.kicad_sch]
2023-12-12 Added Alphanumeric display
    [NMEA-2000-influxdb.kicad_sch, display.kicad_sch]
2023-12-16 Added I2C adresses
    [display.kicad_sch]
2024-01-02 Added Display PCB
    [NMEA-2000-influxdb.kicad_pcb, NMEA-2000-influxdb.kicad_sch, display.kicad_sch]
2024-01-03 Updated Display
    [NMEA-2000-influxdb.kicad_pcb, NMEA-2000-influxdb.kicad_sch, display.kicad_sch]
2024-03-16 Updated schematic
    [NMEA-2000-influxdb.kicad_sch, display.kicad_sch]
2024-03-20 Added Mainboard
    [NMEA-2000-influxdb.kicad_pcb]
2024-04-06 Removed RTC-Module
    [NMEA-2000-influxdb.kicad_sch]
2024-04-06 Added Backup CAN Transceiver Module Switched Push Button for SPST Switch Added Heatsink for LM7805
    [NMEA-2000-influxdb.kicad_sch, display.kicad_sch]
2024-04-06 Added VMOT Added Power LEDs
    [NMEA-2000-influxdb.kicad_sch]
2024-04-06 Updated SN65HVD Module
    [NMEA-2000-influxdb.kicad_sch]
2024-05-02 Cleared up project
    [NMEA-2000-influxdb.kicad_sch]
2024-05-04 Cleared up Schematic
    [NMEA-2000-influxdb.kicad_sch]
2024-05-04 Updated PCB
    [NMEA-2000-influxdb.kicad_pcb]
2024-05-12 Added 3D Models
    [DM3AT-SF-PEJM5--3DModel-STEP-418109.STEP, MicroSD Reader Assembly.stp, S-8254AAVFT-TB-U.stp]
2024-05-12 Added SMD SD-Card
    [NMEA-2000-influxdb.kicad_pcb, NMEA-2000-influxdb.kicad_sch]
2024-05-14 Updated 3d Models and PCB
    [Jumper.step, NMEA-2000-influxdb.kicad_pcb, NMEA-2000-influxdb.kicad_sch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]
2024-05-17 Finished Revision 3
    [NMEA-2000-influxdb.kicad_pcb, NMEA-2000-influxdb.kicad_sch, bom.csv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]
2024-05-23 Finished Schematic Rev 4
    [NMEA-2000-influxdb.kicad_sch]
2024-05-29 Finished Rev 4 Schematics
    [Bme280.stp, NMEA-2000-influxdb-BOM.csv, NMEA-2000-influxdb.kicad_pcb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]
2024-05-29 Added Schematic PDF
    [NMEA-2000-influxdb.kicad_sch]
2024-06-12 Finished Rev 4
    [NMEA-2000-influxdb.kicad_sch, display.kicad_sch]
2024-06-22 Adde diBom
    [NMEA-2000-influxdb.kicad_pcb]
